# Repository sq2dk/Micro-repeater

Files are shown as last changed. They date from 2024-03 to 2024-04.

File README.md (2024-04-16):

# Micro-repeater
Two way radio FM micro repeater based on SA-818 modules

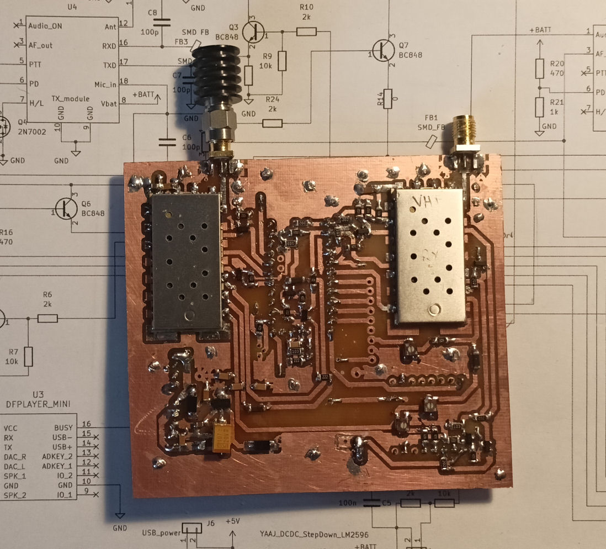
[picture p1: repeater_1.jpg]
Bottom view of second prototype.


This project is by no means complete and finalized. Care must be taken while reproducing, as design might have faults. For radio-amateur use only. You have to have license to experiment with radio transmissions and have to be aware of consequences of your actions!

Repeater can be used to extend usable range of two way portable VHF/UHF radio by placing it in a convenient location between both radios. It consists of receiver (RX) and transmitter (TX) which work at the same time while TX is transmitting everything what is received by RX.
In this project two ready-made TX/RX (SA-818) modules were used. Depending on chosen band of these modules, various band configuration can be achieved. The lowest cost repeater can be done by using 2m / 70cm (cross-band) configuration, since for this you do not need expensive duplexer.

Repository consist of Kicad design files, Arduino code and whatever information might be required.

## Concept:
### -Radio
Small footprint and light weight is achieved by miniature RX/TX modules. Those are based around SDR based chip RDA1847, which is not perfect, but is basically self-contained two-way radio in itself. SA-818 modules consist also microcontroller and power amplifier to achieve about 1W output power. No RF output filtering is made, so at least low-pass filter should be added at the output of TX. RX achieving reasonable sensitivity (better than -120dBm). Communication and set-up of modules is done by serial communication (AT commands). 
### -Microcontroller
Clone of Arduino pro-mini was used. Basically minimal computational power is required, so ATMega328 is more than enough. Small footprint and cost is another benefit. Downside is the programming interface, but almost any USB<->serial TTL interface can be used. Basically it was used, because it was on hand :-).
### -MP3 Player
In some (most?) of the countries, repeaters are required to transmit their call signs aery now and then. This is done by employing small MP3 player module (MP3-TF-16P), which can play MP3 files stored on SD card. On this card various sound files are stored, which also allow transmitting numerical values (such as voltage, temperature etc) by voice. Communication with the module is done by serial protocol.
### -DTMF
DTMF decode module based on MT8870D is added to be able to decode commands sent by user's radio keys. This is fully optional, at the moment requests for voltage, temperature and signal strength are implemented. Others can be coded.
### -Serial communication
As mentioned above, both radio modules and MP3 players are communicating by the serial protocol. All are connected to the same bus, thus additional switches of bus lines (made on transistors) are added, so only one device is able to "talk" with microcontroller at the time. Not perfect, but it works. This has added a lot of complexity to the design, but the principle is easy.
### -Power supply
Two voltages are required - 5V for DTMF module and about 4.3 for MP3 and radio modules. Arduino is also powered by 4.3V, which is fine (you have to use 5V variant). Device can be powered by 5V (from USB) or 7-15V. If you supply 5V, it has to be stabilized. Do not connect both sources at the same time. If you use 5V input jumper pin has to be installed. 5-15V is feed to DC-DC buck converter based on ready module and converted to 4.3V. In case of 7-15V input, 5V is produced by 78L05 linear stabilizer, in case of 5V supply it is feed directly. Reverse-polarity diode is installed, so in case of connection 7-15V short will be made.
### -Others
DS18D20 1-wire temperature sensor can be connected to get temperature readings
2 pins are provided to connect voltage reading. Voltages up to 20V should be fine (voltage divider can be changed in case of other requirements). Calibration of readings is required in software in case of using.

## PCB
PCB is designed to be able to do as single layer at home. Most of the traces are thick, as I was using home-made PCBs for prototyping. In case of homemade PCB recommend to use 2-layer PCB and leave one side with full-copper (ground) layer. Some "bodge" wires are unfortunately required. Complete device has dimensions of approx 10 x 10 x 2 cm. It can definitely be shrunk-down, by re-designing PCB.

## Challenges:
-Power consumption - at the moment, it is not optimized for power consumption. Additional power-save modes are required in software (and in hardware)
-RF interference - modules and their surroundings require additional shielding. On entrance of RX, strong remains of TX transmission is present. Additional shielding of both modules should be made.

Jedrzej Marsz SQ2DK

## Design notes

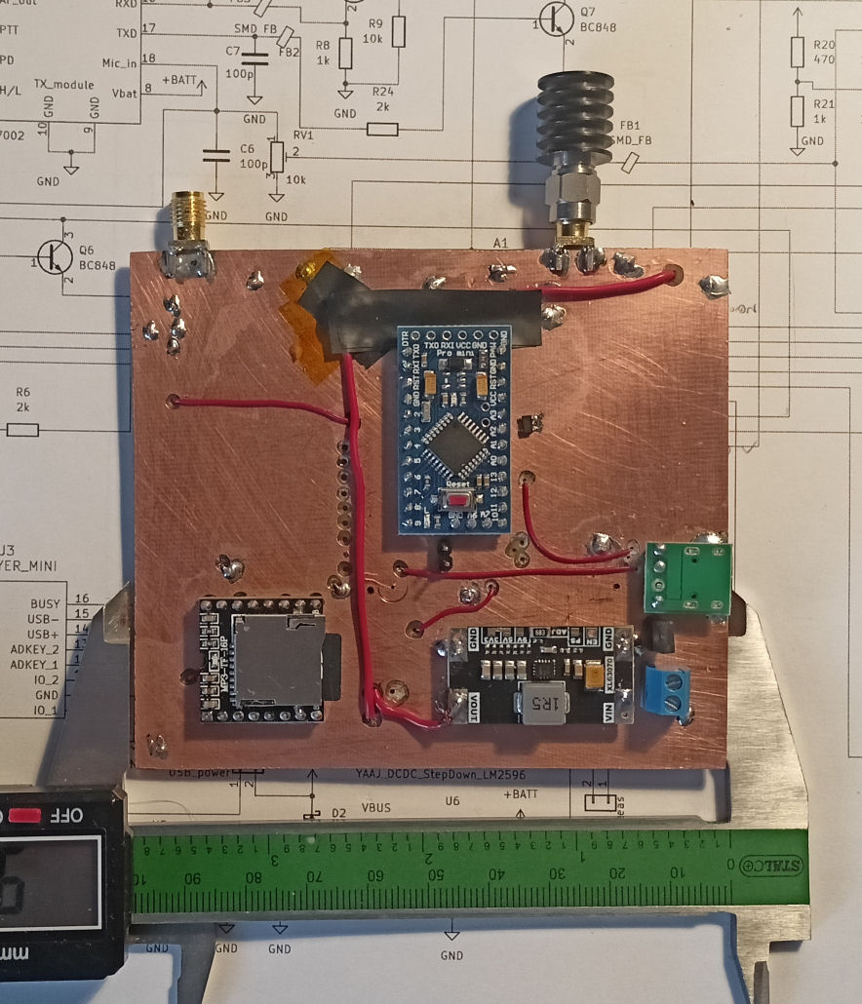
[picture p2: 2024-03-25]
repeater_2.jpg

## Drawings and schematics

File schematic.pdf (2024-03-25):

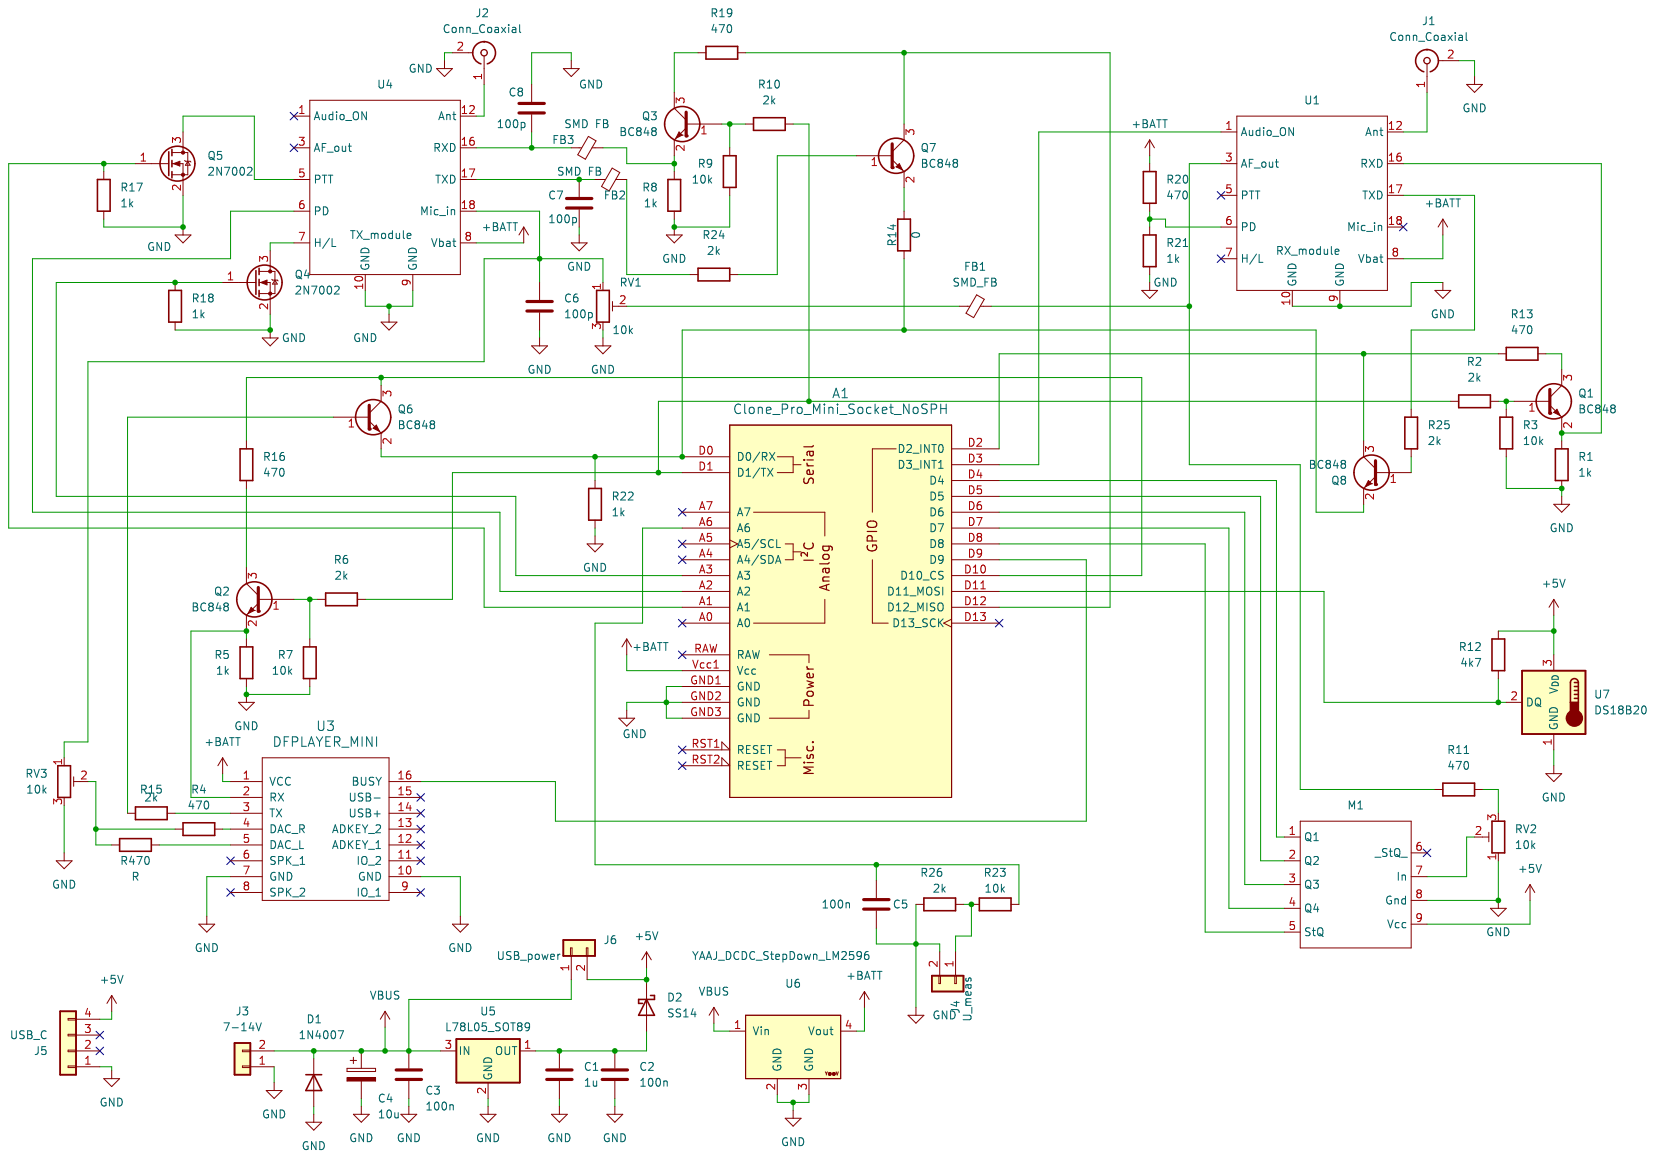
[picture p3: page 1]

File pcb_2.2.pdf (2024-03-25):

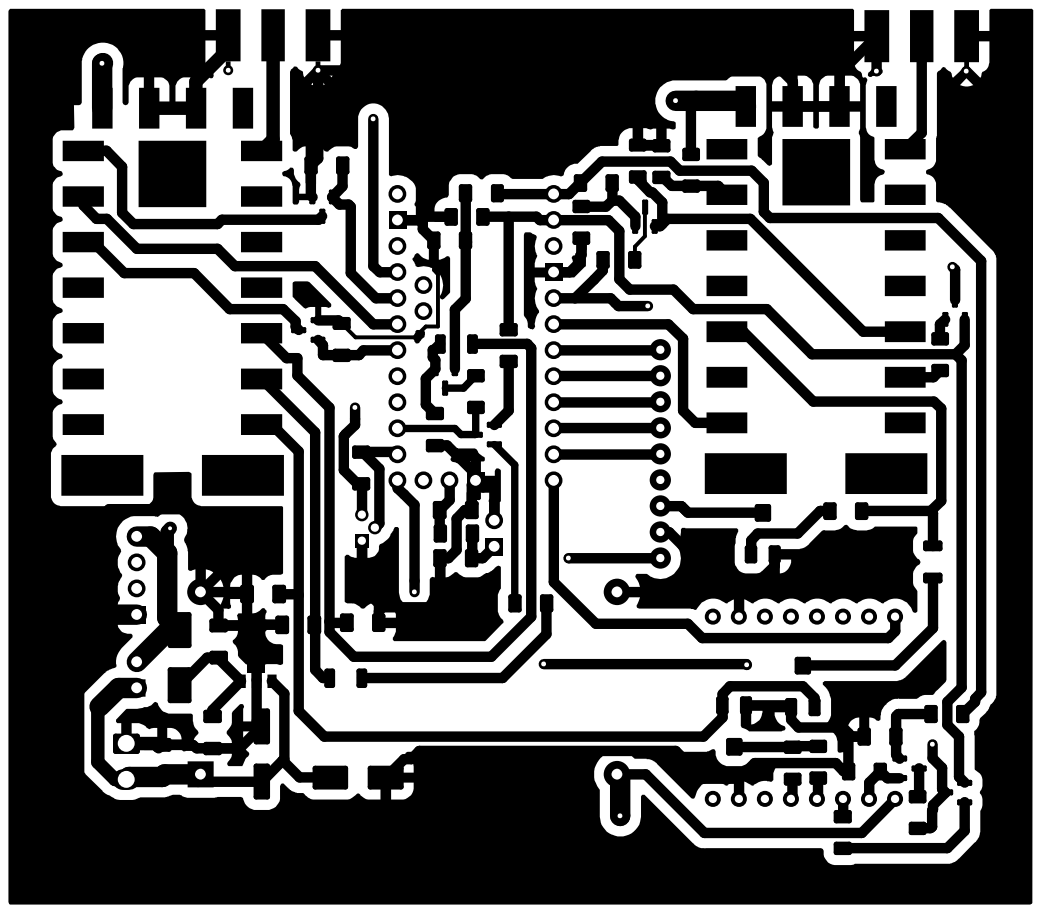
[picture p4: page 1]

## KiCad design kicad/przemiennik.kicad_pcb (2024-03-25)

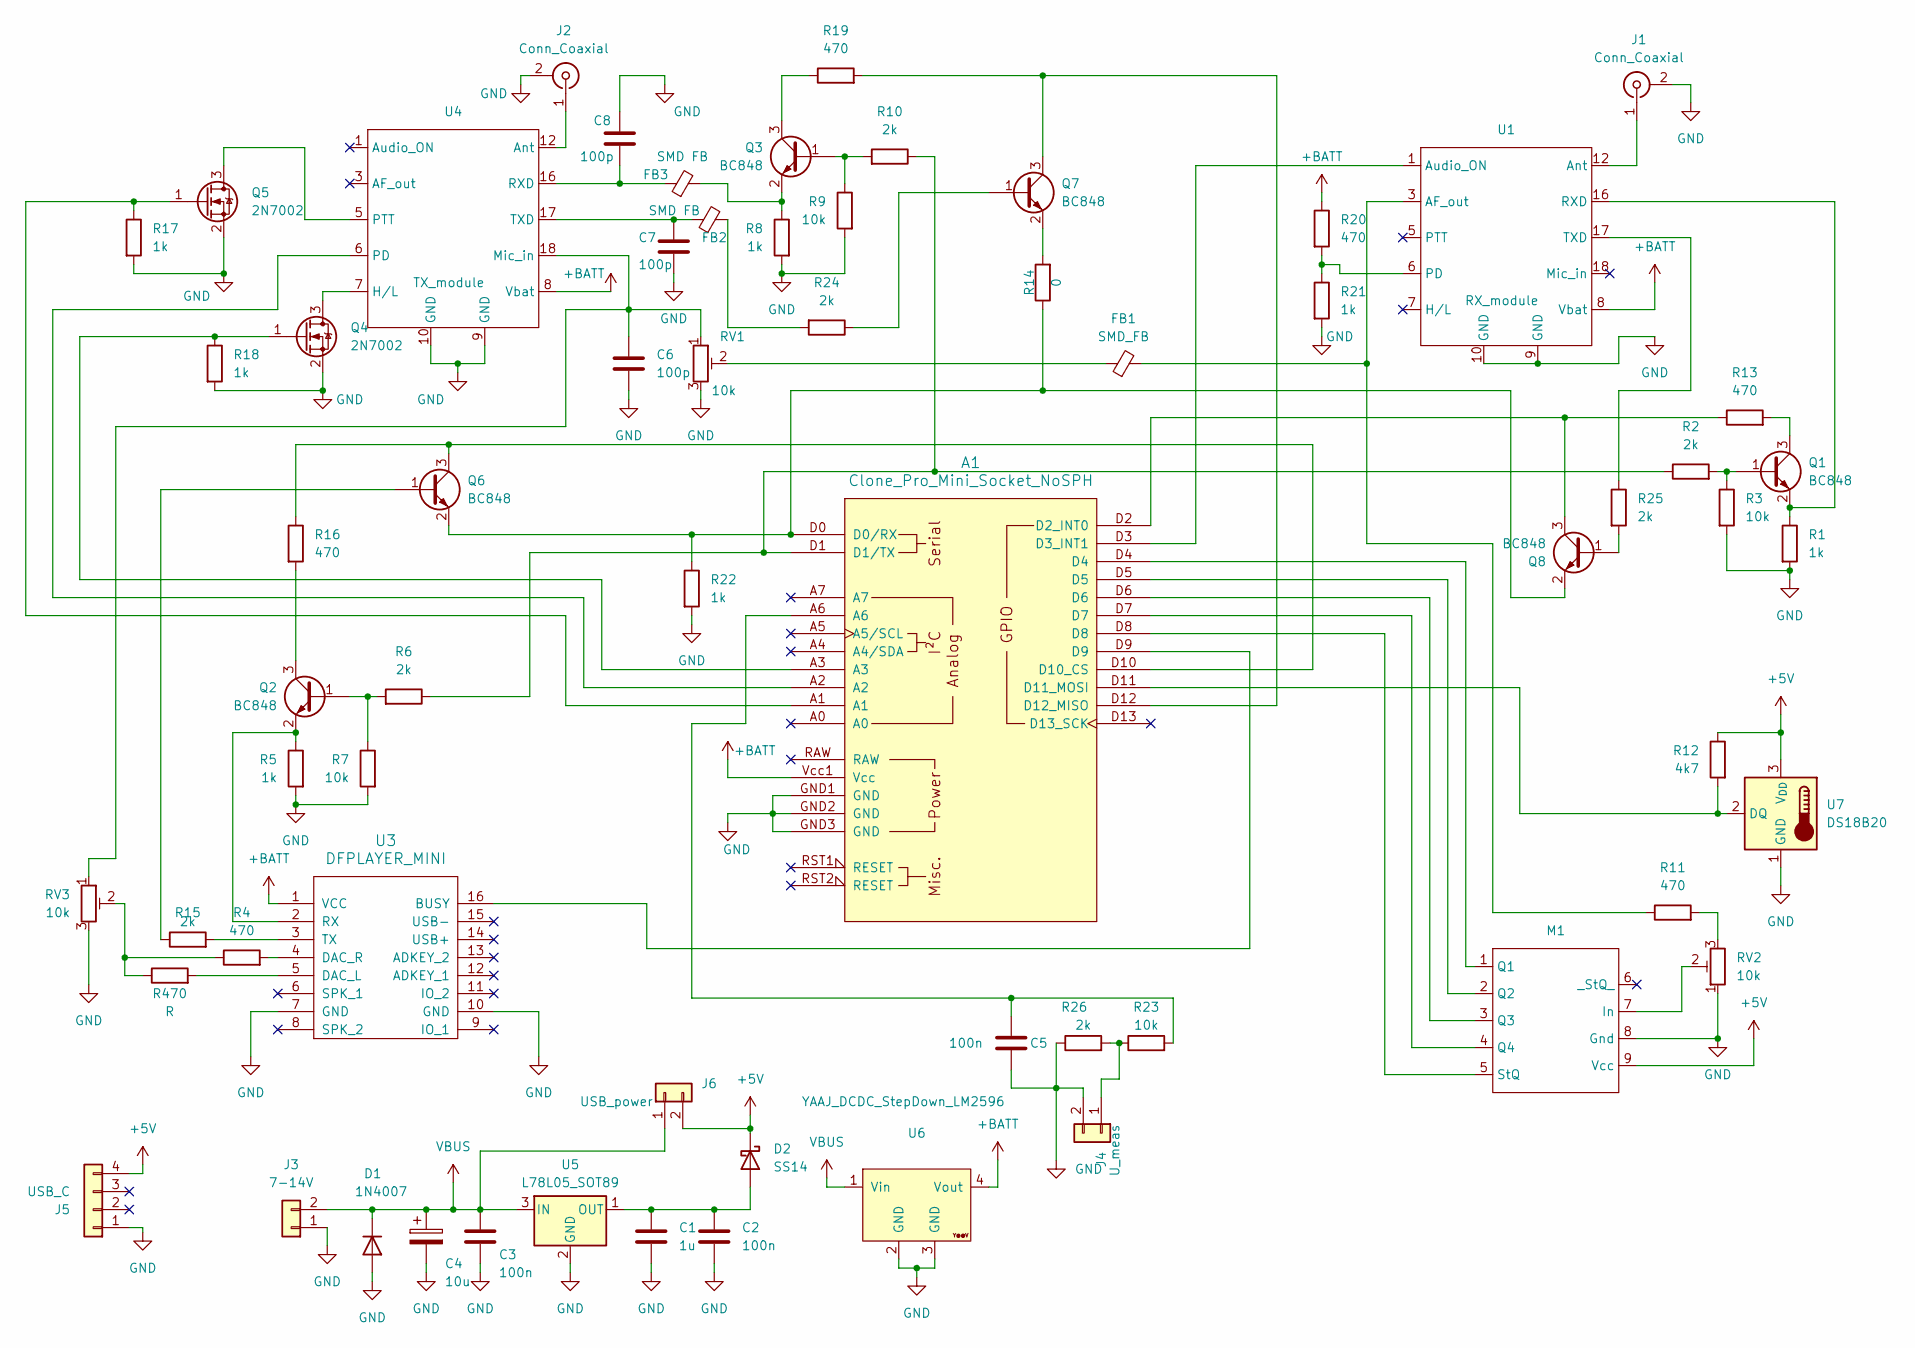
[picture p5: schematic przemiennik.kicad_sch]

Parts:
A1: Clone_Pro_Mini_Socket_NoSPH
C1: 1u; C_1206_3216Metric_Pad1.33x1.80mm_HandSolder
C2, C3, C5: 100n; C_1206_3216Metric_Pad1.33x1.80mm_HandSolder
C4: 10u; CP_Elec_6.3x3
C6, C7, C8: 100p; C_1206_3216Metric_Pad1.33x1.80mm_HandSolder
D1: 1N4007; D_SMB_Handsoldering
D2: SS14; D_SMB_Handsoldering
FB1: SMD_FB; L_1206_3216Metric
FB2, FB3: SMD FB; L_1206_3216Metric
J1, J2: Conn_Coaxial; SMA_Samtec_SMA-J-P-X-ST-EM1_EdgeMount
J3: 7-14V; Wago_734-132_1x02_P3.50mm_Vertical
J4: U_meas; PinHeader_1x02_P2.54mm_Vertical
J5: USB_C; PinHeader_1x04_P2.54mm_Vertical
J6: USB_power; PinHeader_1x02_P2.54mm_Vertical
M1: mt8870_module
Q1, Q2, Q3, Q6, Q7, Q8: BC848; SOT-23
Q4, Q5: 2N7002; SOT-23
R1, R5, R8, R17, R18, R21, R22: 1k; R_1206_3216Metric_Pad1.30x1.75mm_HandSolder
R2, R6, R10, R15, R24, R25, R26: 2k; R_1206_3216Metric_Pad1.30x1.75mm_HandSolder
R3, R7, R9, R23: 10k; R_1206_3216Metric_Pad1.30x1.75mm_HandSolder
R4, R11, R13, R16, R19, R20: 470; R_1206_3216Metric_Pad1.30x1.75mm_HandSolder
R12: 4k7; R_1206_3216Metric_Pad1.30x1.75mm_HandSolder
R14: 0; R_1206_3216Metric_Pad1.30x1.75mm_HandSolder
R470: R; R_1206_3216Metric_Pad1.30x1.75mm_HandSolder
RV1, RV2, RV3: 10k; Potentiometer_Bourns_3314S_Horizontal
U1: RX_module; DRA818
U3: DFPLAYER_MINI; DFPlayer_V2
U4: TX_module; DRA818
U5: L78L05_SOT89; SOT-89-3
U6: YAAJ_DCDC_StepDown_LM2596
U7: DS18B20; TO-92

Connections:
+5V: D2.1 (K), J5.4, J6.2, M1.9 (Vcc), R12.1, U7.3 (V_{DD})
+BATT: A1.Vcc1 (Vcc), R20.1, U1.8 (Vbat), U3.1 (VCC), U4.8 (Vbat), U6.4 (Vout)
GND: A1.GND1 (GND), A1.GND2 (GND), A1.GND3 (GND), C1.2, C2.2, C3.2, C4.2, C5.2, C6.2, C7.2, C8.1, D1.2 (A), J1.2 (Ext), J2.2 (Ext), J3.1, J4.2, J5.1, M1.8 (Gnd), Q4.2 (S), Q5.2 (S), R1.2, R3.2, R5.2, R7.2, R8.2, R9.2, R17.2, R18.2, R21.2, R22.2, R26.1, RV1.3, RV2.1, RV3.3, U1.9 (GND), U1.10 (GND), U3.7 (GND), U3.10 (GND), U4.9 (GND), U4.10 (GND), U5.2 (GND), U6.2 (GND), U6.3 (GND), U7.1 (GND)
unnamed: A1.D0 (D0/RX), Q6.2 (E), Q8.2 (E), R14.1, R22.1
unnamed: A1.D1 (D1/TX), R2.1, R6.1, R10.1
unnamed: A1.D2 (D2_INT0), Q8.3 (C), R13.1
unnamed: A1.D3 (D3_INT1), U1.1 (Audio_ON)
unnamed: A1.D10 (D10_CS), Q6.3 (C), R16.1
unnamed: A1.D11 (D11_MOSI), R12.2, U7.2 (DQ)
unnamed: A1.D12 (D12_MISO), Q7.3 (C), R19.2
unnamed: A1.A6, C5.1, R23.2
unnamed: C1.1, C2.1, D2.2 (A), U5.1 (OUT)
unnamed: FB1.1, RV1.2
unnamed: FB2.2, R24.2
unnamed: J1.1 (In), U1.12 (Ant)
unnamed: J2.1 (In), U4.12 (Ant)
unnamed: J4.1, R23.1, R26.2
unnamed: M1.7 (In), RV2.2
unnamed: A1.D4, M1.1 (Q1)
unnamed: A1.D5, M1.2 (Q2)
unnamed: A1.D6, M1.3 (Q3)
unnamed: A1.D7, M1.4 (Q4)
unnamed: A1.D8, M1.5 (StQ)
unnamed: Q1.1 (B), R2.2, R3.1
unnamed: Q1.3 (C), R13.2
unnamed: Q1.2 (E), R1.1, U1.16 (RXD)
unnamed: Q2.1 (B), R6.2, R7.1
unnamed: Q2.3 (C), R16.2
unnamed: Q2.2 (E), R5.1, U3.2 (RX)
unnamed: Q3.1 (B), R9.1, R10.2
unnamed: Q3.3 (C), R19.1
unnamed: FB3.2, Q3.2 (E), R8.1
unnamed: Q4.3 (D), U4.7 (H/L)
unnamed: A1.A3, Q4.1 (G), R18.1
unnamed: Q5.3 (D), U4.5 (PTT)
unnamed: A1.A1, Q5.1 (G), R17.1
unnamed: Q6.1 (B), R15.1
unnamed: Q7.1 (B), R24.1
unnamed: Q7.2 (E), R14.2
unnamed: Q8.1 (B), R25.2
unnamed: R4.1, R470.1, RV3.2
unnamed: R11.2, RV2.3
unnamed: FB1.2, R11.1, U1.3 (AF_out)
unnamed: R20.2, R21.1, U1.6 (PD)
unnamed: R25.1, U1.17 (TXD)
unnamed: A1.D9, U3.16 (BUSY)
unnamed: R470.2, U3.5 (DAC_L)
unnamed: R4.2, U3.4 (DAC_R)
unnamed: R15.2, U3.3 (TX)
unnamed: C6.1, RV1.1, RV3.1, U4.18 (Mic_in)
unnamed: A1.A2, U4.6 (PD)
unnamed: C8.2, FB3.1, U4.16 (RXD)
unnamed: C7.1, FB2.1, U4.17 (TXD)
VBUS: C3.1, C4.1, D1.1 (K), J3.2, J6.1, U5.3 (IN), U6.1 (Vin)

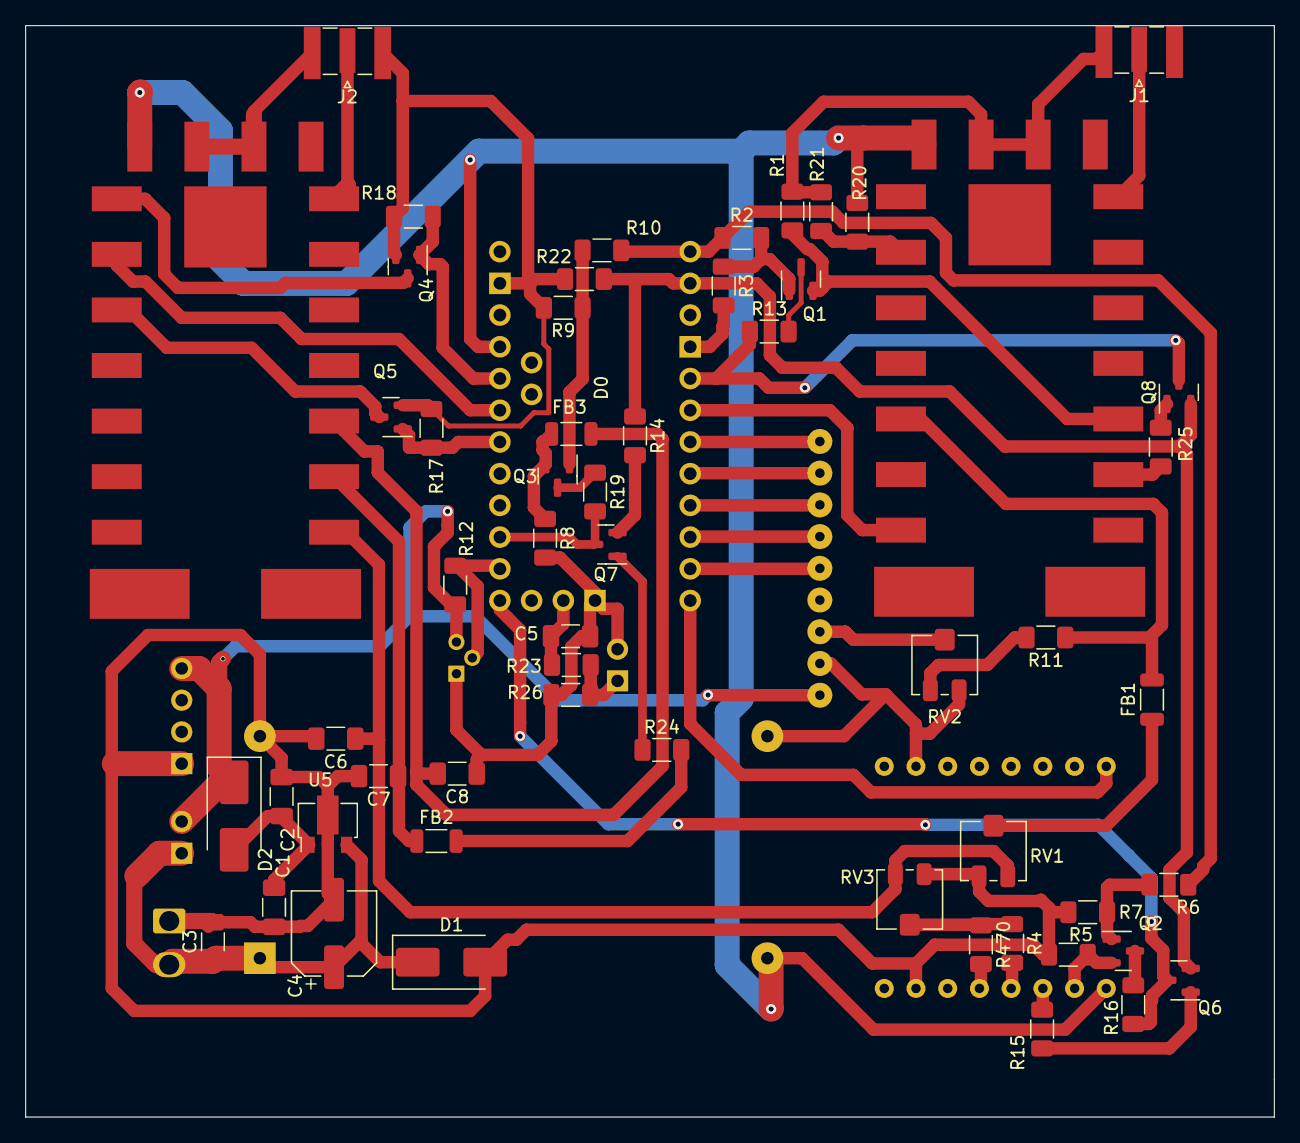
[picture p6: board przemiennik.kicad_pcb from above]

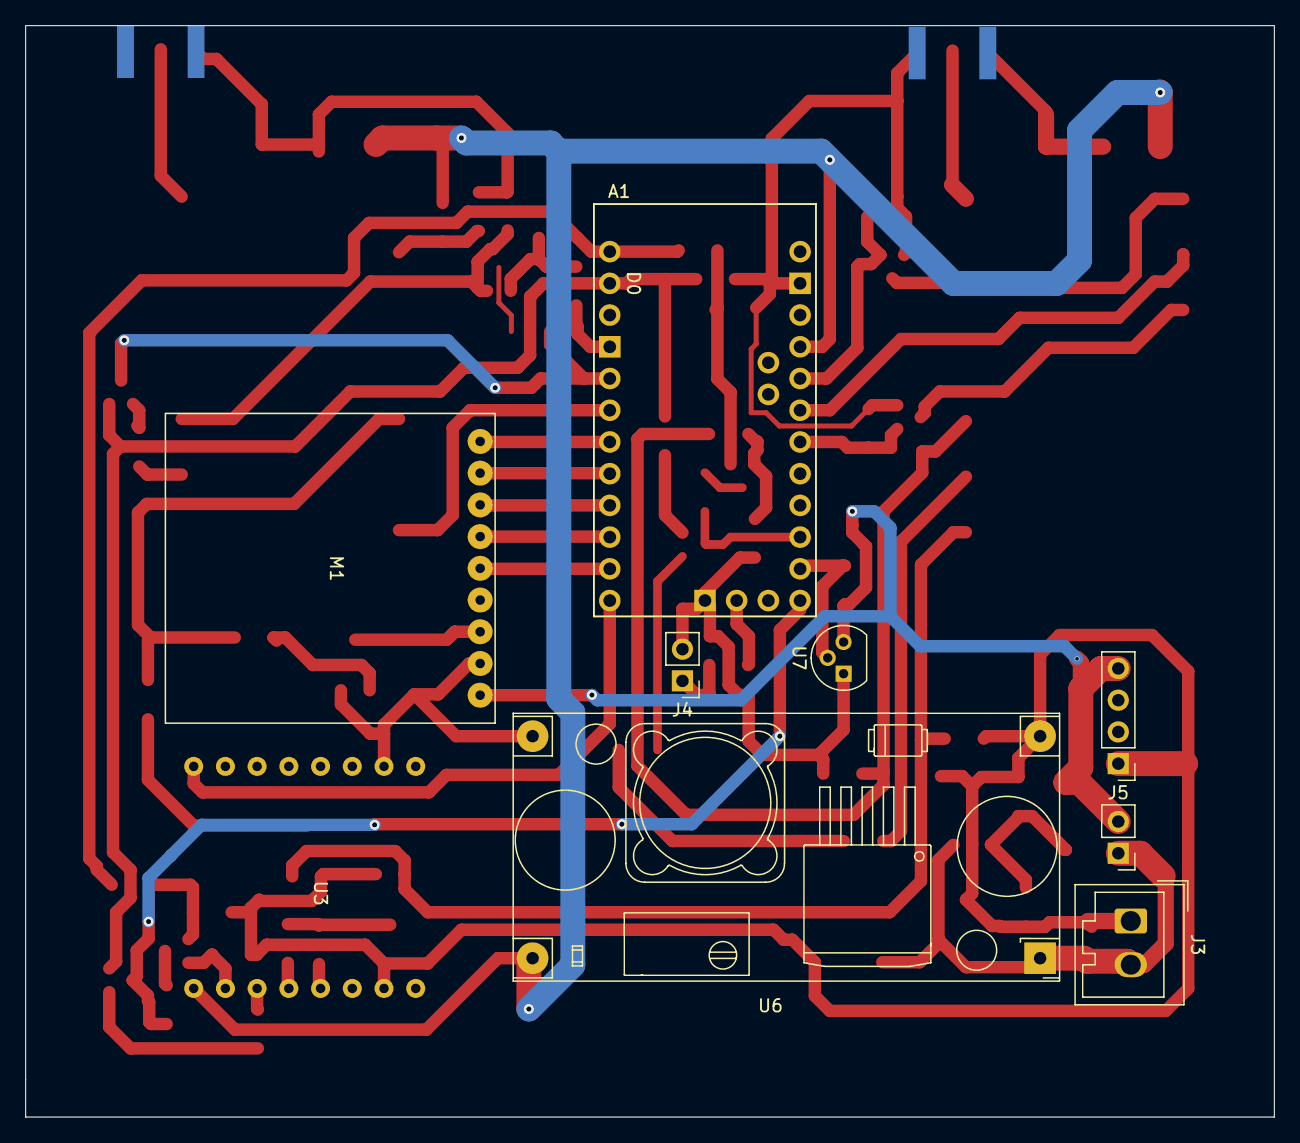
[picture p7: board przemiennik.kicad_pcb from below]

Board: 2 copper layers, 100.0 x 87.4 mm, 65 parts (9 on the bottom side), 54 nets.

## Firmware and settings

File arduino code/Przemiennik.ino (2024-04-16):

#include "przemiennik.h"    //internal config file
#include "mp3tf16p.h"       //mp3 player lib
#include "OneWire.h"        // for temperature sesnor
#include "DallasTemperature.h" // for temperature sesnor https://github.com/milesburton/Arduino-Temperature-Control-Library/
#include "LowPower.h"



#define FPSerial Serial    // we are using hardware serial for MP3player (not software serial)

// #define DEBUG 1

//HardwareSerial *dra_serial;
//dra_serial *Serial;  // same for radio modules...


DFRobotDFPlayerMini myDFPlayer;
OneWire oneWire(OneWire_pin);
// Pass our oneWire reference to Dallas Temperature.
DallasTemperature sensors(&oneWire);

// arrays to hold device address
DeviceAddress insideThermometer;

static boolean transmit_active = false;
static uint8_t beep_one = 0;
unsigned long tail_timer;
unsigned long time_DTMF;
unsigned long last_beep_time;
unsigned long last_signal_change;
unsigned long first_oscilation_time;
unsigned long start_rx_delay;
unsigned long last_transmit_time;
unsigned long callsign_timer;

boolean oscilation_detected = 0;
uint8_t oscilation_count;
uint8_t status_change_detected = 0;
uint8_t power_save_mode = 0;

uint8_t readSerialTimeout()
{
	uint8_t readed = false;
	unsigned long timeout = millis();
	while (millis() - timeout < 500) {
		delay(100);
		//wdt_reset();
		while (Serial.available() > 0) {
#ifdef DEBUG			
			Serial.write(Serial.read());
#else
			Serial.read();
#endif			
			readed = true;
		}
		if (readed == true)break;
	}
#ifdef DEBUG			
	if(!readed){
		Serial.println("Read timeout");
	}
#endif			
	return readed;
}

uint8_t SA818_begin(uint8_t device_pin)
{
	//not a commmand, but for sure
  digitalWrite(device_pin, HIGH);
//	Serial.print("AT\r\n");
  //Serial.print("AT\n\r");
	delay(100);

	for(uint8_t r = 0; r<5; r++){
		Serial.print("AT+DMOCONNECT\r\n");
    //Serial.print("AT+DMOCONNECT\n\r");
    
		if(readSerialTimeout()){
			//got +DMOCONNECT:0<CR><LF>
      delay(100);
      digitalWrite(device_pin, LOW);
			return true;
		}
	}
  delay(100);
  digitalWrite(device_pin, LOW);
	return false;
  
}

uint8_t SA818_setConfig(uint8_t device_pin, uint8_t bw, char* tx_f, char* rx_f, char* tx_ctcss, char* rx_ctcss, uint8_t squelch)
{

	digitalWrite(device_pin, HIGH);
	delay(100); 

	for(uint8_t r=0; r<5; r++){
		Serial.print("AT+DMOSETGROUP=");
		Serial.print(bw); // 0/1
		Serial.print(",");
		Serial.print(tx_f);//134-174/400-480, format to 415.1250
		Serial.print(",");
		Serial.print(rx_f);//format to 415.1250
		Serial.print(",");
		Serial.print(tx_ctcss);//format to 0000
		Serial.print(",");
		Serial.print(squelch); // <= 8
		Serial.print(",");
		Serial.print(rx_ctcss);
		Serial.print("\r\n");

		if(readSerialTimeout()){
      delay(100);
      digitalWrite(device_pin, LOW);
			return true;
		}
	}
  delay(100);
  digitalWrite(device_pin, LOW);
	return false;
}

uint8_t SA818_setVolume(uint8_t device_pin, uint8_t volume)
{
	// Set PTT off, so we can communicate with the uC.
	// Delay for a bit, to finish TX
	digitalWrite(device_pin, HIGH); 
	delay(100);

	if(volume>8) volume = 8;

	//sprintf(this->buffer,"AT+DMOSETVOLUME=%1d\r\n",this->volume);
	Serial.print("AT+DMOSETVOLUME=");
	Serial.print(volume);
	Serial.print("\r\n");
  delay(100);
  digitalWrite(device_pin, LOW); 
  return readSerialTimeout();

}

uint8_t SA818_setFilters(uint8_t device_pin, boolean preemph, boolean highpass, boolean lowpass)
{

	digitalWrite(device_pin, HIGH); 
	delay(100);

	//sprintf(this->buffer,"AT+SETFILTER=%1d,%1d,%1d\r\n",this->preemph,this->highpass,this->lowpass);
	//Serial.print(this->buffer);

	Serial.print("AT+SETFILTER=");
	Serial.print(preemph);
	Serial.print(",");
	Serial.print(highpass);
	Serial.print(",");
	Serial.print(lowpass);
	Serial.print("\r\n");

  delay(100);
  digitalWrite(device_pin, LOW);
	//return true; //must be +DMOSETFILTER: X (X=0->ok, X=1-fail)
	return readSerialTimeout();

}


void setup() {
  // put your setup code here, to run once:

  // pin mode config
  
  pinMode(Player_pin, OUTPUT);
  pinMode(Receiver_pin, OUTPUT);
  pinMode(Transmitter_pin, OUTPUT);

  pinMode(TX_PD, OUTPUT);
  pinMode(TX_PTT, OUTPUT);
  pinMode(TX_Low_power, OUTPUT);
  pinMode(Player_busy, INPUT);
  
  digitalWrite(TX_PTT, LOW);
  digitalWrite(TX_Low_power, LOW);            //LOW=high power, HIGH=low power

  pinMode(RX_Af_out, INPUT);
  attachInterrupt(digitalPinToInterrupt(RX_Af_out), Signal_received, CHANGE);
  //LowPower.attachInterruptWakeup(RX_Af_out), Signal_received, CHANGE);

  pinMode(DTMF_0, INPUT);
  pinMode(DTMF_1, INPUT);
  pinMode(DTMF_2, INPUT);
  pinMode(DTMF_3, INPUT);
  pinMode(DTMF_STQ, INPUT);

  pinMode(Player_busy, INPUT);


  digitalWrite(Receiver_pin, LOW);
  digitalWrite(Transmitter_pin, LOW);
  digitalWrite(Player_pin, LOW);
  
  
  Serial.begin(9600);               //hardware serial setup

  sensors.getAddress(insideThermometer, 0);
  
  myDFPlayer.begin(FPSerial);

  // Configure RX module
  
  SA818_begin(Receiver_pin);
  SA818_setConfig(Receiver_pin, RX_bandwith, RX_frequency, RX_frequency, RX_CTCSS, RX_CTCSS, RX_squelch);  //RX and TX frequency same for RX module
  SA818_setVolume(Receiver_pin, RX_volume); // 0 to 8
  SA818_setFilters(Receiver_pin, 1, 0, 0);   //pin, preemph ON/OFF, higpass ON/OFF, lowpass ON/OFF
  digitalWrite(Receiver_pin, LOW);

 // Configure RX module
  digitalWrite(TX_PD, HIGH);
  delay(100);
  SA818_begin(Transmitter_pin);
  SA818_setConfig(Transmitter_pin, TX_bandwith, TX_freuency, TX_freuency, TX_CTCSS, TX_CTCSS, TX_squelch);  //RX and TX frequency same for RX module
  SA818_setVolume(Transmitter_pin, TX_volume); // 0 to 8
  SA818_setFilters(Transmitter_pin, 1, 0, 0);   //pin, preemph ON/OFF, higpass ON/OFF, lowpass ON/OFF
 
  digitalWrite(Transmitter_pin, LOW);   //finish comms with transmitter

  digitalWrite(Player_pin, HIGH);  //Transmitting only to MP3 player
  
  if (!myDFPlayer.begin(FPSerial, false)) {  //Use serial to communicate with mp3.
    digitalWrite(Player_pin, LOW);  
    Serial.println(F("Unable to begin:"));
    Serial.println(F("1.Please recheck the connection!"));
    Serial.println(F("2.Please insert the SD card!"));
    while(true){
      delay(0); // Code to compatible with ESP8266 watch dog.
    }
  }
  myDFPlayer.volume(15);  //Set volume value. From 0 to 30
  
  if (Repeater_callsign_active) play_file_no(1);  //play repeater callsign file (file No1)
  
  
  digitalWrite(Player_pin, LOW); //finish transmitting to MP3 player
  
  //digitalWrite(TX_PTT, HIGH);
  //digitalWrite(TX_PD, LOW);
  
}

uint8_t read_RSSI()
{
  uint8_t temp_player_pin = digitalRead(Player_pin);
  uint8_t tmp_result = 0;
  digitalWrite(Player_pin, LOW); //finish transmitting to MP3 player

  digitalWrite(Receiver_pin, HIGH); 
	//delay(100);
	Serial.print("RSSI?\r\n");
	delay(100);
  unsigned long timeout = millis();
	while (millis() - timeout < 500) {
		delay(100);
		//wdt_reset();
		while (Serial.available() > 0) {
    uint8_t tmp_r = Serial.read();
    //Serial.print(char(tmp_r));
   // Serial.print((tmp_r));
		if (tmp_r==61)   //we have "="  (replay will be "RSSI=XXX")
     { 
      uint8_t fd = Serial.read();  //first digit
      uint8_t sd = Serial.read();  //second digit
      uint8_t td = Serial.read();  //third digit
      tmp_result = fd-48;
      if (sd>47) {tmp_result = (tmp_result*10+(sd-48));}
      if (td>47) {tmp_result  =(tmp_result*10+(td-48));}
     }		
	  }  //while
  }

  digitalWrite(Receiver_pin, LOW); 
  digitalWrite(Player_pin,temp_player_pin);
  return tmp_result;

}

uint8_t read_DTMF()
{
  uint8_t DTMF_code=0;
  
  DTMF_code=digitalRead(DTMF_3);
  DTMF_code=DTMF_code<<1;
  DTMF_code+=digitalRead(DTMF_2);
  DTMF_code=DTMF_code<<1;
  DTMF_code+=digitalRead(DTMF_1);
  DTMF_code=DTMF_code<<1;
  DTMF_code+=digitalRead(DTMF_0);
  return DTMF_code;
}

void play_file_no(uint8_t filenumber)
{
  digitalWrite(Player_pin, HIGH);  //Transmitting only to MP3 player
  digitalWrite(TX_PD,HIGH); //makes sure, that TX module is awake
  digitalWrite(TX_PTT,HIGH);  //switch on TX
  if (power_save_mode) {   //if we are in power save mode, go back to normal
    Serial.print(0x0B);
    //Serial.print(0x7EFF060B000000EF); 
    delay(500);}
  power_save_mode = 0;

  if (!transmit_active) { delay(700); }                  //if not on, wait since it takes a long time to activate transmiter...
  myDFPlayer.play(filenumber);         //transmit reuested file 
  delay(200);                 //smoe more time to start playing...
  while (!digitalRead(Player_busy)){   //wait untill finis playing...
       delay(10);
  }
  if (!transmit_active){        //if we are not in the middle of transmission
    digitalWrite(TX_PTT,LOW);  //switch off TX
    last_transmit_time = millis();
   
  } 
}

void play_number(float number, uint8_t vol_tem = 0)
{
  uint8_t filetoplay;
  uint8_t hundreds;
  uint8_t tens;
  uint16_t number_to_play = number;
  uint8_t float_part;

  digitalWrite(Player_pin, HIGH);  //Transmitting only to MP3 player
  //Serial.print(0x0B); //wake up MP3 module
  float_part=10*(number-number_to_play);
  boolean transmit_was_active=transmit_active;

  digitalWrite(TX_PD,HIGH);  //makes sure, that TX module is awake
  digitalWrite(TX_PTT,HIGH);  //switch on TX
  if (power_save_mode) {   //if we are in power save mode, go back to normal
    Serial.print(0x0B);
    delay(500);}
  power_save_mode = 0;

  if (!transmit_active) delay(700);                  //if not on, wait since it takes a long time to activate transmiter...
  transmit_active=1;
  
  if ((vol_tem==1) || (vol_tem==2)) {play_file_no(2+(vol_tem*2));}  //we are playing temperature / voltage
  if (vol_tem==3) {play_file_no(8);} // or signal strength
  if (number_to_play>100) {
     hundreds=number_to_play/100;
     number_to_play=number_to_play-(hundreds*100);
     if (number_to_play!=0) play_file_no(hundreds+40);  
  }
  if (number_to_play>20) {
    tens=(number_to_play/10);
    play_file_no(tens+30);
    number_to_play=number_to_play-(tens*10);
  }
  if (!((number>19) && (number_to_play==0))) {  //play number from 0 to 19 if it is not zero after full number of tens (not to say "twenty zero")
  play_file_no(number_to_play+10); }

  if (float_part>0){
    play_file_no(9);  //przecinek
    play_file_no(float_part+10);
  }
  if ((vol_tem==1) || (vol_tem==2)) {play_file_no(3+(vol_tem*2));}  //we are playing temperature / voltage

  if (!transmit_was_active) {
    digitalWrite(TX_PTT,LOW);
    last_transmit_time = millis();
    
  }
  transmit_active=transmit_was_active;
}

float read_voltage()
{
  return (analogRead(Analog_in)/40);        //10-bit - max value 1024 - 5V, voltage divider set to 5 (25Vin=1024) - input voltage divider 2k / 10k
}

void loop() {
  // put your main code here, to run repeatedly:

//digitalWrite(Player_pin, HIGH);  //Transmitting only to MP3 player
  
  if (status_change_detected) RX_stats_change();

  if ((millis() - callsign_timer > Repeater_callsign_time) && (Repeater_callsign_active)) {    //send repeater callsign every Repeater_callsign_time
    callsign_timer = millis();
    //myDFPlayer.sendStack(0x0B);
    play_file_no(1);  //play repeater callsign file (file No1)
  }

 if ((transmit_active) && (millis() > (tail_timer + 2000)) && (digitalRead(RX_Af_out))) {  //if we are not receiving anything transmitting and more than 2000ms from last rx signal
  digitalWrite(TX_PTT,LOW);  //switch off TX
  last_transmit_time = millis();
  transmit_active=0;         // set TX flag to 0

 }

 if ((digitalRead(DTMF_STQ)) && (millis()>(time_DTMF+500)) && (DTMF_Enabled)) {   //if we have DTMF detected and more than 0.5s from last DTMF.
  uint8_t temp_num=read_DTMF();
  play_number(temp_num);
  if (temp_num==11) {
    play_number(read_voltage(),2);
  }
  if (temp_num==12) {
    sensors.requestTemperatures();
    play_number(sensors.getTempC(insideThermometer),1);
  }
  if (temp_num==10) {
    uint8_t RSSI_read = read_RSSI();
    //play_number(152);
    play_number(RSSI_read, 3);
  }
  time_DTMF=millis();
 }

 if ((power_save_enable) && (power_save_mode == 0) && (millis() > (last_transmit_time + power_save_delay)) && (!transmit_active)) {  //switch to power save mode (power down transmitter) after power_save_delay since last transmision
  power_save_mode = 1;
  digitalWrite(TX_PD, LOW);   //power down transmitter
  digitalWrite(Receiver_pin, LOW);  // make sure, that we only talking to MP3 player
  digitalWrite(Transmitter_pin, LOW);  //
  digitalWrite(Player_pin, HIGH);  //Transmitting only to MP3 player
  Serial.print(0x0A);  //mp3 module should go to sleep as well...
   
  delay(100);
  digitalWrite(Player_pin, LOW);  //


  LowPower.powerDown(SLEEP_FOREVER, ADC_OFF, BOD_OFF);    //puts arduino to sleep - wakes on hardware interrupt.

 }


}

void RX_stats_change()                   
{
    status_change_detected = 0;   //clears status change flag to be ready for new event

    if ((!transmit_active) && (!digitalRead(RX_Af_out)) && (!oscilation_detected)) {    //begin of receiving (not transmiting)
    
       uint8_t continous_signal = 1;
    
       start_rx_delay = millis();
       //we cannot use nointerrupts, since it will disable millis()
    
       delay(50);

       while (millis() < (RX_delay + start_rx_delay))   //checking if we have continous signal for RX_delay time...
          {
            if (digitalRead(RX_Af_out)) { continous_signal=0;}    //check if there is no braks in the signal for RX_delay preriod
            if (status_change_detected) { continous_signal=0; }  //if in the meantime status have changed
          }
       if (continous_signal) {   //if signal was continous for this time
        
           transmit_active=1;
           digitalWrite(TX_PD,HIGH);  //makes sure, that TX module is awake
           digitalWrite(TX_PTT,HIGH);
           power_save_mode = 0;
           digitalWrite(Player_pin, HIGH);  //Transmitting only to MP3 player

           Serial.print(0x0B);  //MP3 player in normal mode

           delay(200);
           last_transmit_time = millis();
         }
      
    }

  if ((transmit_active) && (digitalRead(RX_Af_out))) {    //we are transmitting, but there is no more signal...
      //noInterrupts();        //temporarly disable interupts - not to call same function again...
      
      // beep only if, last signal change was >0.5s ago, last time beeped more tan minimum time and beep is enabled
      if ((Beep_on) && (millis()  > (minimum_beep_time + last_beep_time)) && ((millis() - last_signal_change) > 500)) {
         myDFPlayer.play(beep_one+2);    //play beep of various tone
         last_beep_time = millis();

      }

      beep_one++;         //alternative beep tones...
      if (beep_one>1) beep_one=0;

      if ((digitalRead(RX_Af_out))) {  //if there is still no more signal...
        tail_timer = millis();
      }
      //interrupts();
      

  }
}

void Signal_received(){              // function called on change of signal detect pin

//With receiver module we have problem with self-oscilation in case of small signal. Signal appears and disapears in short successions, causing beep to activate
//millis() is not changing values in this routine (ISR), so any routines using those have to be made outside of this space...
  
  //noInterrupts();
if (osc_det_active)    //following only if oscilation detection is switched on
{
  if ((millis() ) < (last_signal_change + osc_det_timeout)) {   //if last change of signal was lestt than ... we need to check for oscilations
      if (oscilation_count==0) { first_oscilation_time = millis();}  //if this is first occurance, note the time
      oscilation_count++;  
  }
  if (oscilation_count > 8) {   //if oscilations hae been detected, switch off transmitter
    oscilation_detected = 1;
    transmit_active = 0;
    digitalWrite(TX_PTT,LOW);
    last_transmit_time = millis();
  }
  if ((millis()) > (last_signal_change + osc_det_timeout)) { 
    oscilation_count = 0;
    oscilation_detected = 0;
  }
}
 

  digitalWrite(LED_pin, !digitalRead(RX_Af_out));   // show status of signal on LED
      


  status_change_detected = 1;          //this informs main routine, that some status change was detected

  last_signal_change = millis();       //takes tiem of tat event

  
  
  //digitalWrite(TX_PTT, !digitalRead(RX_Af_out));

}

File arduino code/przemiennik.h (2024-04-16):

// Pins definitions

//serial comms RX enable pins

#define Player_pin 10
#define Receiver_pin 2
#define Transmitter_pin 12

#define LED_pin 13

//oter pins
// #define Analog_in A0  //old design
#define Analog_in A6  // new design
#define Player_busy 9
#define TX_PTT  A1    // transmit on low impedance
#define TX_PD   A2    //power down
#define TX_Low_power A3
#define RX_Af_out  3 // receiver active - signal present - LOW

#define DTMF_Enabled 1  //0 - disable, 1 enabled
#define DTMF_0 4
#define DTMF_1 5
#define DTMF_2 6
#define DTMF_3 7
#define DTMF_STQ 8
// #define DTMF_STQ 11  //old design

#define OneWire_pin 11
//#define OneWire_pin 8  // old design

// Receier module configuration

#define RX_frequency "145.1125"   //for cross-band
//#define RX_freuency "430.5125"   //for 70cm only repeater
#define RX_bandwith 0     // 0=12.5kHz, 1=25kHz
#define RX_volume 6       //0=min, 8=max
#define RX_CTCSS "0010"   //"0010"=94.8 
#define RX_squelch 5       //0-8

#define RX_delay 100     // 100ms - delay for avoid opening on super-short signals - minum length of signal opening repeater

// Transmitter module configuration
#define TX_freuency "438.1125"  //for cross-band
// #define TX_freuency "438.1125"  //for 70cm rpt
#define TX_bandwith 0     // 0=12.5kHz, 1=25kHz
#define TX_volume 3       //0=min, 8=max
#define TX_CTCSS "0010"   //"0010"=94.8 
#define TX_squelch 8

//Beeps 
#define Beep_on 0  //0-off, 1-on
#define minimum_beep_time 2000   // minimum time in ms between beeps

//Repeater callsign set-up
#define Repeater_callsign_active 1   // 1-active (repeater introduces itself every Repeater_callsign_time), 0-repeater does not introduces itself
#define Repeater_callsign_time 600000   //in ms : 600000 - every 10 minutes

//Power saving
#define power_save_enable 1       // 1- power save enabled, 0 - power save disabled
#define power_save_delay 10000    //10s (10000ms)  delay after receiving a signal when repeater goes to low power mode.

//oscilation detection - rapid (osc_det_timeout) changes of signal / no signal states could indicate of self-oscilations - happens sometimes when TX module is beeing received on RX module.
#define osc_det_active 1  //oscilation protection on=1, off=0
#define osc_det_timeout 500 // [ms]    - 

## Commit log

2024-03-25 Updated files, power save mode added
2024-04-16 Corrected some errors, improved power save
    [Przemiennik.ino, przemiennik.h]
